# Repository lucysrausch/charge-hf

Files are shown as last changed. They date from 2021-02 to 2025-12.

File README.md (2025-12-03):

# GaN Class-D Wireless Power Amplifier

I designed this board because I wanted a signal generator that was more capable than just generating a static waveform.
For familiarizing myself with wireless power transfer and getting a feeling for antenna and magnetic design, I wanted a source-meausure-unit (SMU) for RF,
something that could generate and also measure RF output. I also wanted all settings and measurements to be easily controllable and readable such that I could easily script testbenches in python for plotting parameter sweeps, or prototype control loops critical for real-world WPT like resonance tracking or constant output power control.

I finished this project in winter 2020, and it became an invaluable tool throughout 2021 for designing a custom wireless charging solution.

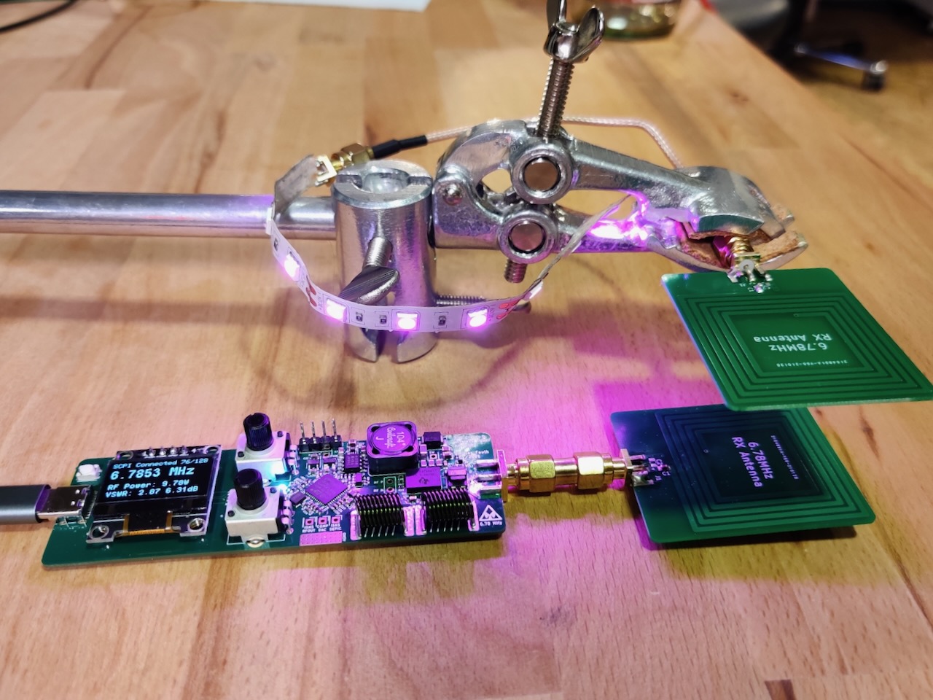
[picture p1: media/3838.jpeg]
WPT Demo Setup

*Assembled development board showing real-time status on OLED display: frequency, RF power, and VSWR measurements.*
*Demonstration setup: PCB spiral coil antennas (transmit and receive) wirelessly powering an LED strip at 6.78 MHz.

## Features

- **6.78 MHz ISM Band Operation** - Optimized for the AirFuel/Qi extended power profile frequency band
- **Software-Defined RF Generation** - Real-time frequency and deadtime adjustment via software
- **STM32G4 HRTIM** - Built around the STM32G474 with 184 ps RF PWM resolution (5.4 GHz effective clock)
- **Integrated SEPIC Converter** - Programmable amplifier supply voltage (0–20V) with input current limiting
- **SCPI over USB CDC** - Standard instrument control protocol for automated test benches
- **OLED Status Display** - Real-time frequency, power, and VSWR monitoring
- **Analog Knob Inputs** - Two potentiometers which can be read via SCPI to control any parameter. (or you can use these ADC inputs to measure ie. voltage and current in the WPT receiver and plot them along input power for efficiency sweeps

## Applications

- Wireless power transfer research and development
- Antenna impedance matching and tuning, efficiency testing
- Inductive heating experiments, plasma generation
- Generic educational RF / power electronics platform

## Hardware Specifications

| Parameter | Value |
|---|---|
| Operating Frequency | 10 kHz – 10 MHz |
| HRTIM Resolution | 184 ps (144 MHz × 32 multiplier) |
| Deadtime Range | 0–511 counts (×8 prescaler, ~1.1 ns steps) |
| Amplifier Supply | 0–20V (SEPIC regulated) |
| Input Current Limit | Programmable, default 3A |
| Input Voltage | 5V USB-C |
| Control Interface | USB CDC (Virtual COM Port) |
| MCU | STM32G474 (170 MHz Cortex-M4F) |

## PCB Design

### 3D Rendering

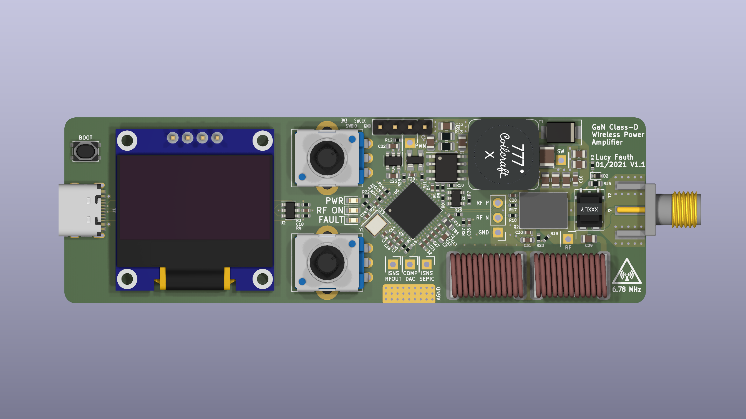
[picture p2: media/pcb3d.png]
3D PCB Render

*3D render of the assembled board with all components*

### Board Layout

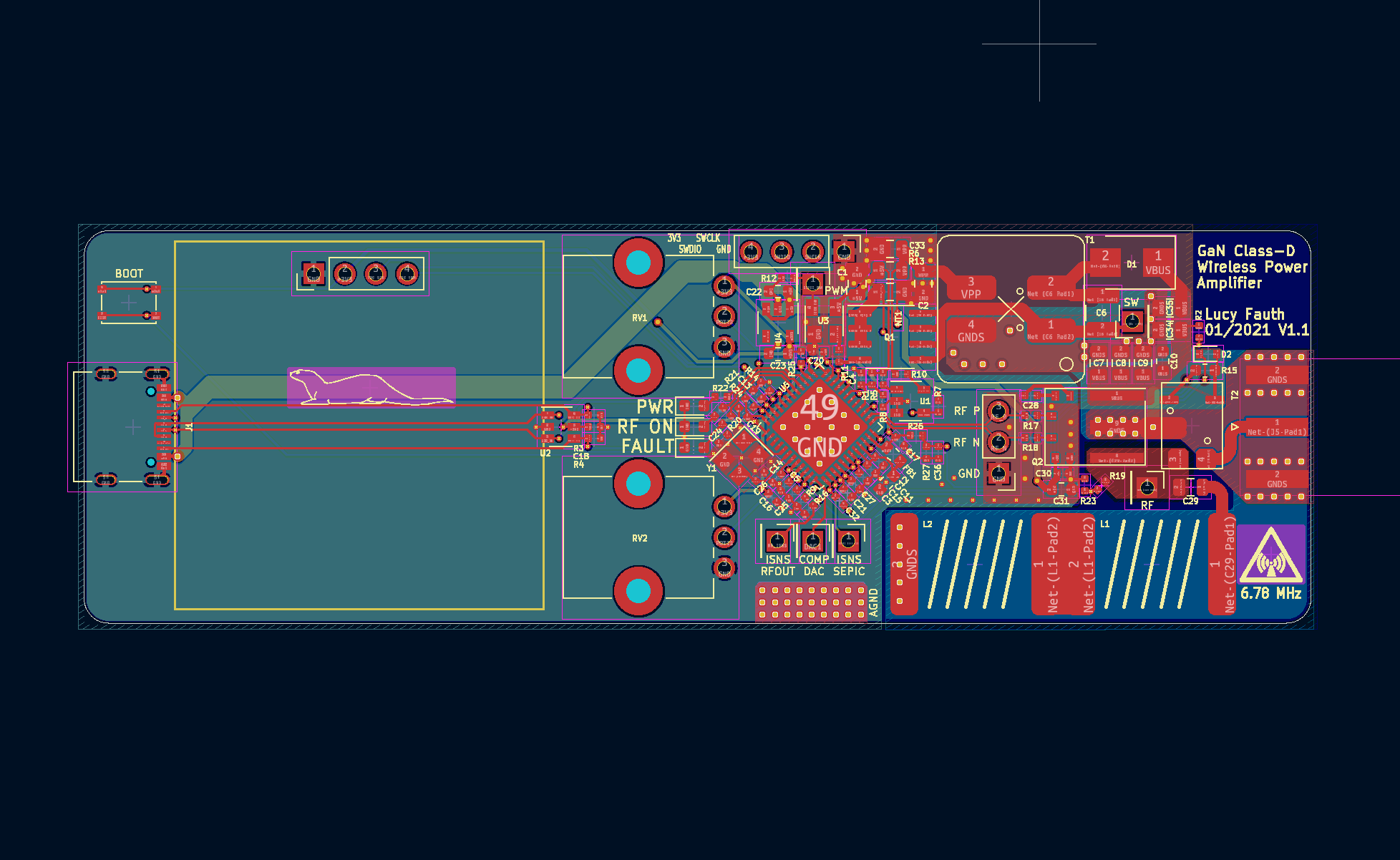
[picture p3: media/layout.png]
PCB Layout

*Full board layout showing component placement: USB-C input (left), OLED display, SEPIC converter (top right), STM32G4 MCU, GaN half-bridge (center right), and output matching network (bottom right)*

### Critical Design: Ground Plane and Return Path

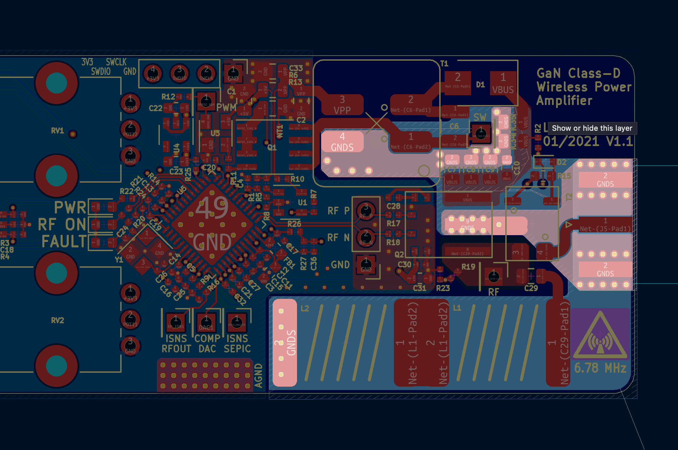
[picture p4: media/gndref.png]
GND Reference Plane

*PCB layout highlighting the ground plane structure around the GaN switching stage*

High-frequency switching at 6.78 MHz with fast edge rates demands careful attention to parasitic inductance in the power loop. Key design decisions implemented in this layout:

**Minimizing Loop Inductance:**
- **Tight Component Placement** - The GaN FETs, gate drivers, and decoupling capacitors are placed as close as possible to minimize the physical area of the switching current loop
- **Direct Via Stitching** - Multiple vias connect the top-side ground pads directly to the internal ground plane, reducing the inductance of the return path
- **Solid Ground Reference** - An unbroken ground plane beneath the switching node provides a low-inductance return path for high-frequency currents with a single net tie to DGND
- **Thermal Relief Considerations** - Ground connections to the FET source pads use sufficient via count to handle both thermal dissipation and the high-frequency return currents

## Schematic

📄 **[Download Full Schematic (PDF)](hardware/schematic_V1.2/charge-hf.pdf)**

The schematic is organized into functional blocks:

```
┌─────────────────┐   ┌─────────────────┐   ┌─────────────────┐   ┌─────────────────┐
│   USB-C Input   │──▶│   SEPIC DCDC    │──▶│  GaN Half-Bridge│──▶│   RF Output     │
│   + ESD Prot.   │   │   5V → 0-20V    │   │   LMG5200       │   │   I & U Sense   │
└────────┬────────┘   └────────┬────────┘   └────────┬────────┘   └─────────────────┘
         │                     │                     │
         │            ┌────────┴────────┐            │
         └───────────▶│   STM32G474     │-───────────┘
                      │   HRTIM + ADC   │
                      │   USB CDC SCPI  │
                      └─────────────────┘
```

## Circuit Design Notes

### Power Stage: LMG5200 GaN Half-Bridge

The heart of the RF amplifier is the **Texas Instruments LMG5200**, a fully integrated 80V/10A GaN half-bridge power stage. This device integrates both high-side and low-side GaN FETs along with their gate drivers in a single 6×8mm QFN package.

**Why use an integrated module?**

- **Minimized Parasitics** - The gate driver and GaN FETs are co-packaged with optimized bond wire lengths, achieving lower gate loop inductance than any discrete solution. This is critical at 6.78 MHz where even 1nH of stray inductance causes significant ringing.
- **Simplified Layout** - A single component eliminates the need to route high-speed gate drive signals across the PCB, reducing EMI and layout complexity.

### SEPIC DC-DC Converter

The amplifier supply (VPP) is generated by a SEPIC topology, chosen for its ability to both step-up and step-down. This allows operation from 5V USB while generating 0–20V for the GaN stage.

**Key components:**

- **Si4058 (Q1)** - Low Rds(on) N-channel MOSFET handles the primary switching
- **MIC4416 (U3)** - Low-side gate driver with enable control, driven directly from STM32 HRTIM Timer D

**Feedback and control:**

- **Voltage Sensing** - A resistive divider (100k/5.1k) scales VPP down to ADC range
- **Current Sensing** - A 10mΩ shunt (R13) with a Si8540 current sense amplifier measures input current for overcurrent protection and constant power control
- **Digital Control Loop** - The STM32 implements a PI controller in the HRTIM repetition interrupt, adjusting duty cycle based on voltage error with current limiting

### USB Power Input

The design operates from USB-C with proper PD support:

- **USBLC6-4 (U2)** - ESD protection on D+/D- and CC lines
- **CC1/CC2 Resistors (R3, R4)** - 5.1kΩ pull-downs advertise the device as a UFP (sink) for default 5V/3A
- **UCPD Peripheral** - The STM32G4's built-in USB-PD controller connects to CC1/CC2 for potential USB-PD negotiation (firmware support for higher voltages possible)

### RF Output Network

The Class-D output is filtered and can be impedance-matched to an antenna:

- **LC Resonant Tank (L1, L2, C29)** - Two 390nH inductors and a 1µF capacitor form a series-resonant network tuned near 6.78 MHz. The tank filters the square wave output and provides the sinusoidal current needed for efficient WPT.
- **CST7030-020LB (T2)** - A 1:20 turns ratio current transformer plus shunt resistor are used for sensing AC output current

### STM32G474 Configuration

The STM32G474CB provides the digital control:

- **HRTIM Timer C** - Generates complementary PWM for the GaN half-bridge with programmable deadtime
- **HRTIM Timer D** - Drives the SEPIC converter with separate frequency/duty control
- **ADC2** - Continuous DMA-driven sampling of voltages, currents, and potentiometer inputs
- **DAC1/DAC3** - Provide reference voltages for the analog comparators (overcurrent protection)
- **I2C1** - Drives the OLED status display
- **USB** - CDC virtual COM port for SCPI communication

## SCPI Command Reference

The amplifier implements SCPI (Standard Commands for Programmable Instruments) over USB CDC. Connect using any serial terminal or VISA library at the default USB CDC settings.

### Identification Commands

| Command | Description | Example Response |
|---|---|---|
| `*IDN?` | Query device identification | `Manufacturer,Model,Serial,Version` |
| `*RST` | Reset device to default state | - |
| `*TST?` | Self-test query | `0` (pass) or `1` (fail) |
| `*CLS` | Clear status registers | - |
| `*OPC?` | Operation complete query | `1` |

### Measurement Commands

| Command | Description | Returns |
|---|---|---|
| `MEASure:VOLTage:DC:INput?` | Read USB input voltage | Voltage in V (float) |
| `MEASure:VOLTage:DC:OUTput?` | Read amplifier supply voltage | Voltage in V (float) |
| `MEASure:CURRent:DC:INput?` | Read input current | Current in A (float) |
| `MEASure:VOLTage:DC:CONTrol? <n>` | Read potentiometer voltage | Voltage in V (float) |

**Example:**
```
> MEAS:VOLT:DC:IN?
< 5.032

> MEAS:VOLT:DC:OUT?
< 12.45

> MEAS:CURR:DC:IN?
< 0.856

> MEAS:VOLT:DC:CONT? 1
< 1.65
```

### Configuration Commands

| Command | Parameters | Description |
|---|---|---|
| `CONFigure:VOLTage:DC:OUTput <V>` | Voltage (0–30V) | Set amplifier supply voltage |
| `CONFigure:CURRent:DC:INput <A>` | Current (0–3A) | Set input current limit |
| `CONFigure:FREQuency <Hz>` | Frequency (10000–15000000) | Set RF output frequency |
| `CONFigure:DEADtime <rising>,<falling>` | 0–511 each | Set half-bridge deadtime |

**Example:**
```
> CONF:VOLT:DC:OUT 15
< OK

> CONF:FREQ 6780000
< OK

> CONF:DEAD 20,20
< OK
```

### System Commands

| Command | Description |
|---|---|
| `SYSTem:ERRor?` | Query and clear oldest error |
| `SYSTem:ERRor:COUNt?` | Query number of errors in queue |
| `SYSTem:VERSion?` | Query SCPI version |
| `STATus:QUEStionable?` | Query questionable status register |

## Python Examples

Example scripts are provided in the [`software/`](software/) directory demonstrating SCPI communication via PyVISA.

Thanks to SCPI integration for both setting parameters and reading output power, it is very easy to build custom testbenches to characterize ie. efficiency over frequency and plot the results using matplotlib or similar.

### Basic Control - [`control.py`](software/control.py)

This script provides interactive control using the two onboard potentiometers. It continuously reads the knob positions via `MEAS:VOLT:DC:CONTrol?`, maps them to frequency (1–8 MHz) and output voltage (0–30V), and updates the amplifier settings in real-time. The display shows actual measured values including calculated input power.

**Usage:**
```bash
python software/control.py
```

### Custom Scripts

For custom automation, connect using PyVISA with the `@py` backend:

```python
import pyvisa as visa
rm = visa.ResourceManager('@py')
amp = rm.open_resource("ASRL/dev/ttyACM0::INSTR")
print(amp.query("*IDN?"))
```

On Windows, the resource string will be `ASRL<n>::INSTR` where `<n>` is the COM port number assigned to the USB CDC device.

## Building the Firmware

### Prerequisites

- ARM GCC Toolchain
- STM32CubeMX (for regenerating HAL code if needed)
- OpenOCD or ST-Utils for flashing

### Compilation

```bash
cd firmware
make
```

### Flashing

```bash
# Using OpenOCD
openocd -f interface/stlink.cfg -f target/stm32g4x.cfg -c "program build/main.elf verify reset exit"

# Or using ST-Link utility
st-flash write build/main.bin 0x8000000
```

### Known bugs

The board features a push button connected to the boot select pin of the STM32. In theory, this would allow the STM32 to enter DFU mode and allow to flash the board without the need for a programmer. Unfortunatly, despite a strong pull-down resistor, the GPIO connected to the gate driver for the SEPIC DC-DC seems to go high when entering DFU. This turns on Q1, but without PWM, it just shorts the USB input and triggers an overcurrent event on the USB port the device is plugged into.

The workaround is to simply not assemble this button, and always flash the board via SWD.

## License

- Hardware design files: MIT license 
- Firmware: MIT license 
- Software: MIT license
- 3rd party Firmware: BSD 3-Clause (STM32 HAL), BSD 2-Clause (SCPI library)

## Author

Lucy Fauth - Rev 1.2 (February 2021)

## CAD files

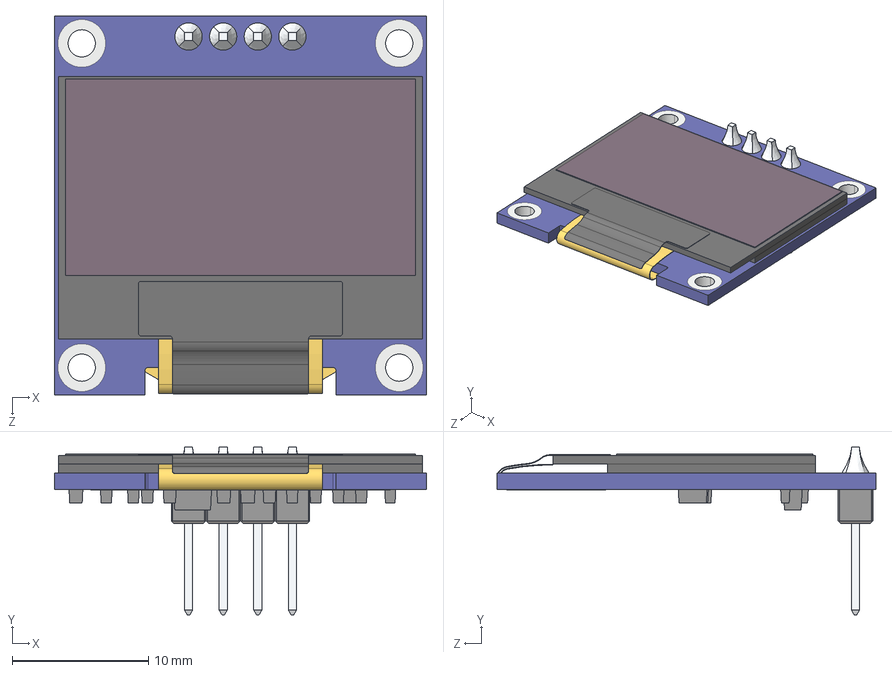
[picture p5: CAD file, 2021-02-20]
hardware/3d/OLED TFT 0.96 inch 64x128 monochrome.STEP
27.3 x 12.3 x 27.8 mm

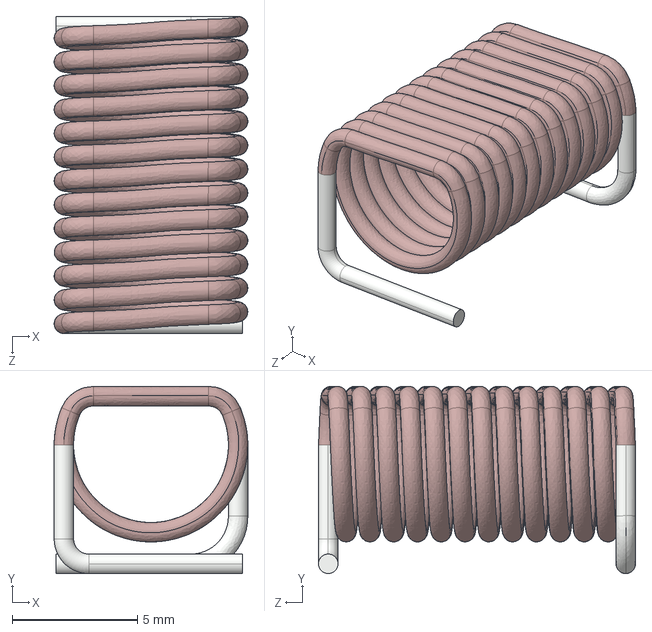
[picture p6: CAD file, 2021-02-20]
hardware/3d/Coilcraft-2929SQ-391.STEP
7.75 x 7.49 x 12.7 mm

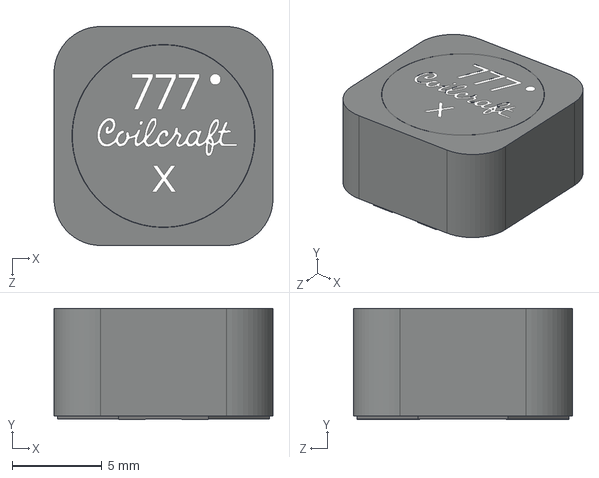
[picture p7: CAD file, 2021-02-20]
hardware/3d/Coilcraft-MSD1260.STEP
12.2 x 6.20 x 12.2 mm

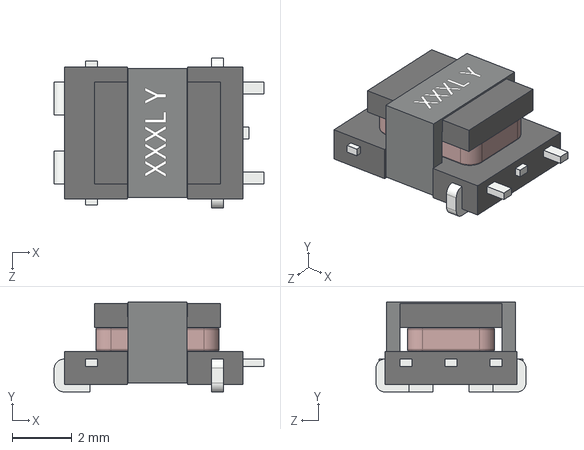
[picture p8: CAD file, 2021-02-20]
hardware/3d/Coilcraft-CST7030.STEP
7.00 x 3.00 x 5.00 mm

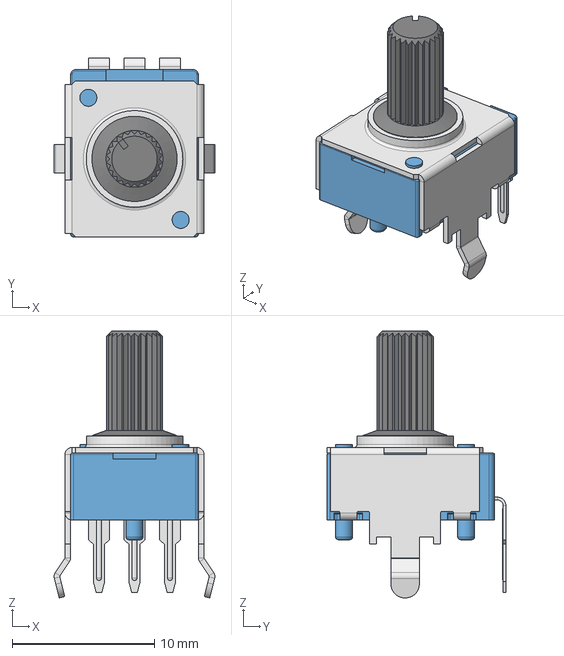
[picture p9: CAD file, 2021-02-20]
hardware/3d/R-0904N-L-15KS.step
11.3 x 12.6 x 18.8 mm

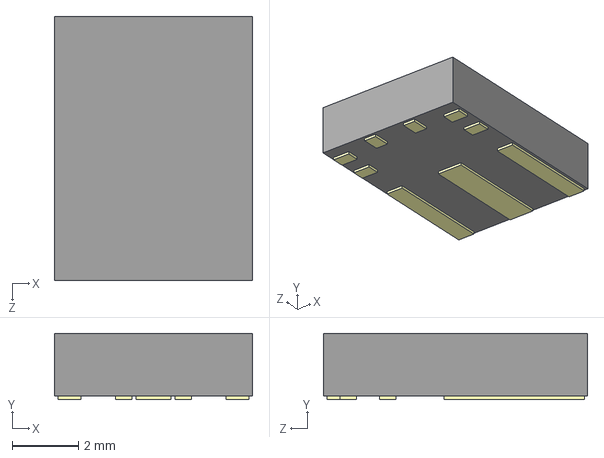
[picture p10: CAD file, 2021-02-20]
hardware/3d/User Library-QFM9_6x8x2mm_LMG5200.STEP
6.00 x 2.00 x 8.00 mm

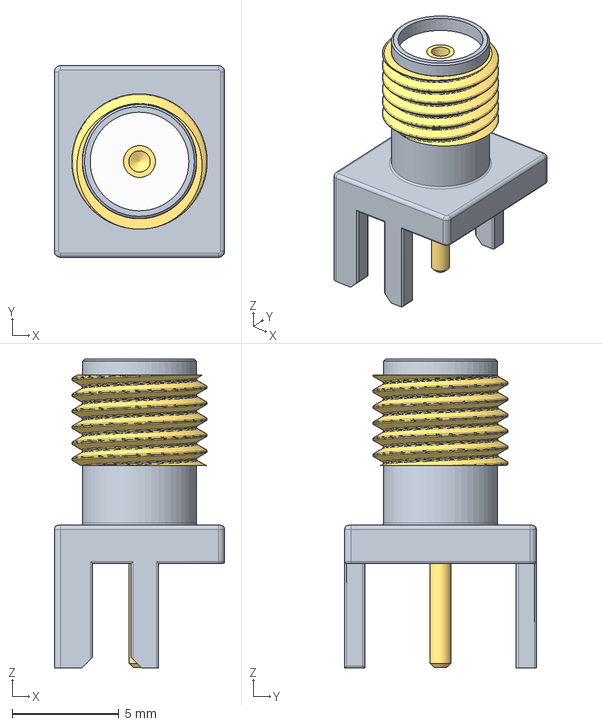
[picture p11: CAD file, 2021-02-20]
hardware/3d/SMA-20.stp
8.00 x 9.00 x 14.5 mm

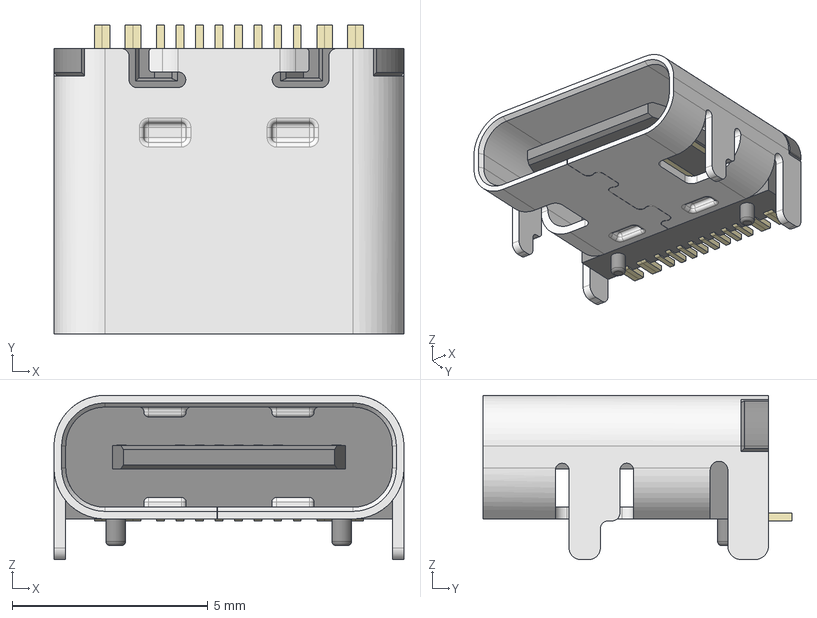
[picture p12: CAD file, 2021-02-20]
hardware/3d/HRO_TYPE-C-31-M-12.step
8.95 x 7.90 x 4.20 mm

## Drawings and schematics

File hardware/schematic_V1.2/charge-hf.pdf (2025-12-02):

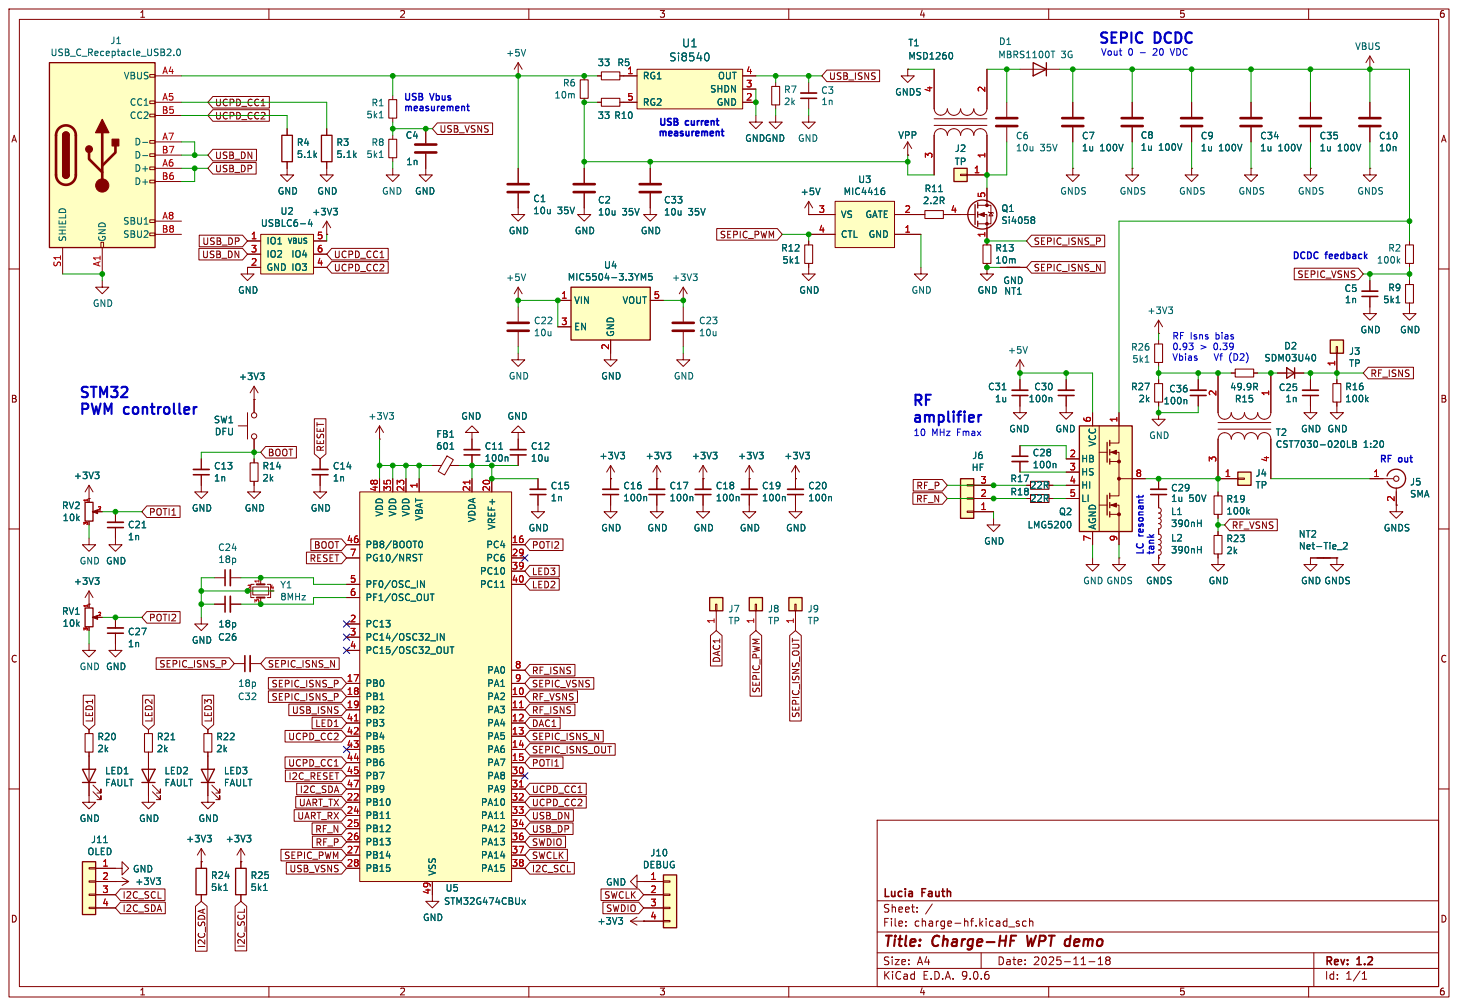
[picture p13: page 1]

1 3 RV1 2 10k GND GND GND GND

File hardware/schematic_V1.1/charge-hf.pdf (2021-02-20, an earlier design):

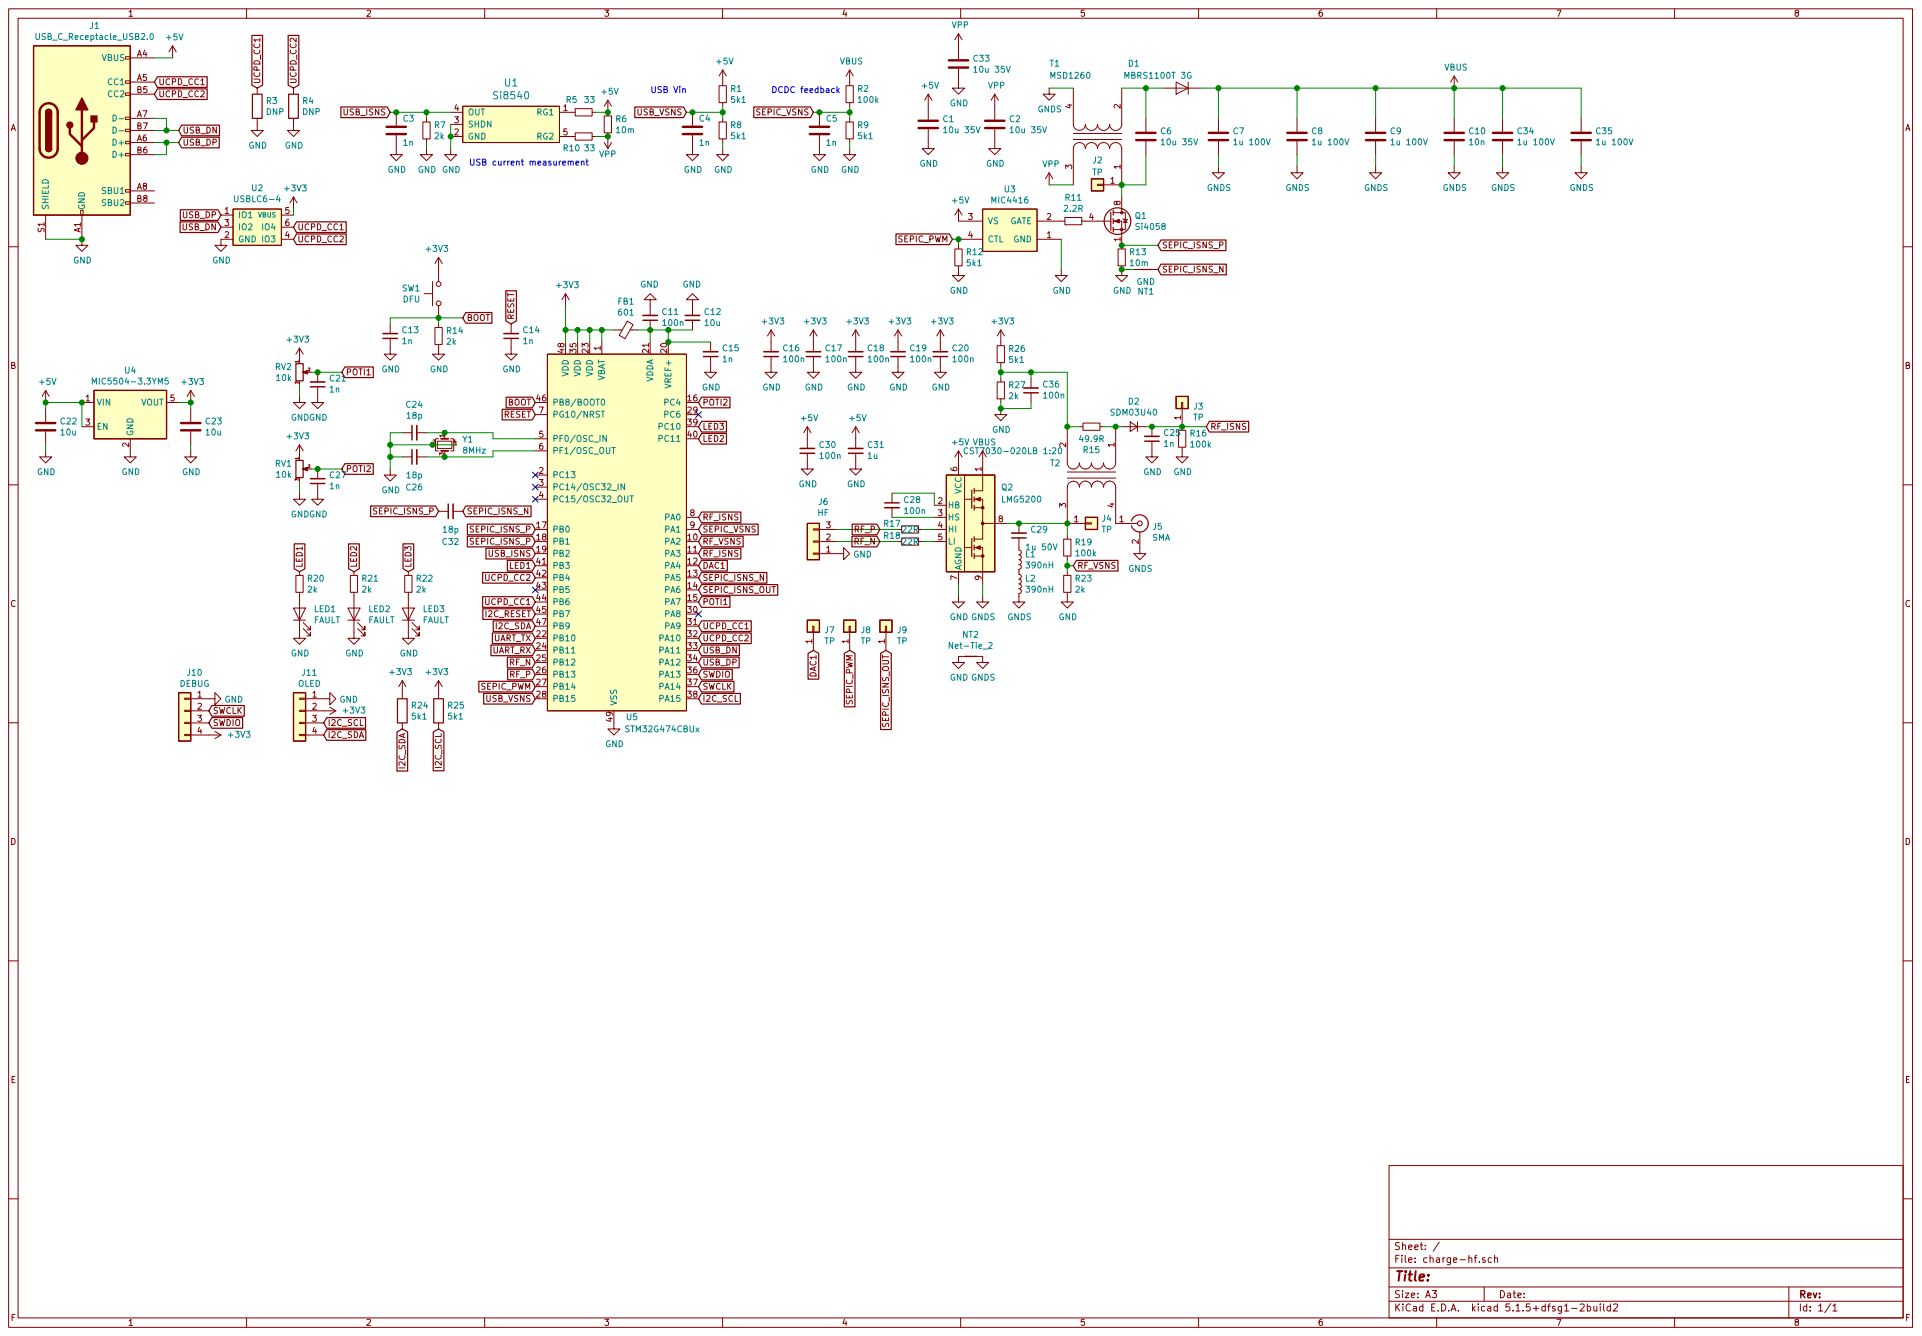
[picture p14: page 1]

File: charge-hf.sch Sheet: /

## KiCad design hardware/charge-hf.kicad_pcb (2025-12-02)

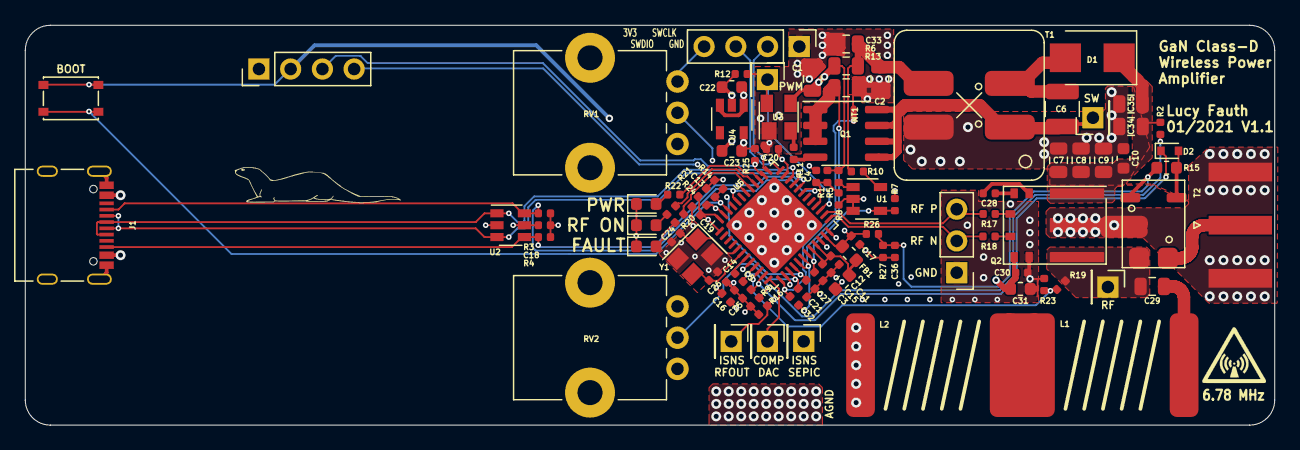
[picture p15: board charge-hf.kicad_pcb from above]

Board: 4 copper layers, 100.0 x 32.0 mm, 96 parts (0 on the bottom side), 55 nets.

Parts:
C1, C2, C33: 10u 35V; C_0805_2012Metric
C3, C4, C5, C13, C14, C15, C21, C25, C27: 1n; C_0402_1005Metric
C6: 10u 35V; C_1210_3225Metric
C7, C8, C9, C34, C35: 1u 100V; C_0805_2012Metric
C10: 10n; C_0603_1608Metric
C11, C16, C17, C18, C19, C20, C28, C30, C36: 100n; C_0402_1005Metric
C12, C22, C23: 10u; C_0603_1608Metric
C24, C26, C32: 18p; C_0402_1005Metric
C29: 1u 50V; C_0805_2012Metric
C31: 1u; C_0603_1608Metric
D1: MBRS1100T 3G; D_SMB
D2: SDM03U40; D_SOD-523
FB1: 601; L_0603_1608Metric
J1: USB_C_Receptacle_USB2.0; USB_C_Receptacle_Palconn_UTC16-G
J2, J3, J4, J7, J8, J9: TP; PinHeader_1x01_P2.54mm_Vertical
J5: SMA; SMA_Amphenol_132289_EdgeMount
J6: HF; PinHeader_1x03_P2.54mm_Vertical
J10: DEBUG; PinHeader_1x04_P2.54mm_Vertical
J11: OLED; PinHeader_1x04_P2.54mm_Vertical
L1, L2: 390nH; 2929SQ
LED1, LED2, LED3: FAULT; LED_0603_1608Metric
NT1: GND; NetTie-2_SMD_Pad0.5mm
Q1: Si4058; SOIC-8_3.9x4.9mm_P1.27mm
Q2: LMG5200; Texas_MOF0009A
R1, R8, R9, R12, R24, R25, R26: 5k1; R_0402_1005Metric
R2, R16, R19: 100k; R_0402_1005Metric
R3, R4: DNP; R_0402_1005Metric
R5, R10: 33; R_0402_1005Metric
R6, R13: 10m; R_0805_2012Metric
R7, R14, R20, R21, R22, R23, R27: 2k; R_0402_1005Metric
R11: 2.2R; R_0402_1005Metric
R15: 49.9R; R_0603_1608Metric
R17, R18: 22R; R_0402_1005Metric
RV1, RV2: 10k; Potentiometer_Bourns_PTV09A-1_Single_Vertical
SW1: DFU; SW_SPST_PTS810
T1: MSD1260
T2: CST7030-020LB 1:20; CST7030
U1: Si8540; SOT-23-5
U2: USBLC6-4; SOT-23-6
U3: MIC4416; SOT-143
U4: MIC5504-3.3YM5; SOT-23-5
U5: STM32G474CBUx; QFN-48-1EP_7x7mm_P0.5mm_EP5.6x5.6mm
Y1: 8MHz; Crystal_SMD_3225-4Pin_3.2x2.5mm

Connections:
+3V3: C16.2, C17.2, C18.2, C19.2, C20.2, C23.1, FB1.2, J10.4, J11.2, R24.1, R25.1, R26.1, RV1.1, RV2.1, SW1.1, U2.5, U4.5, U5.1, U5.23, U5.35, U5.48
+5V: C1.1, C22.1, C30.2, C31.2, J1.A4, J1.A9, J1.B4, J1.B9, Q2.6, R1.1, R5.2, R6.1, U3.3, U4.1, U4.3
BOOT: C13.2, R14.1, SW1.2, U5.46
DAC1: J7.1, U5.12
GND: C1.2, C2.2, C3.2, C4.2, C5.2, C11.2, C12.2, C13.1, C14.1, C15.1, C16.1, C17.1, C18.1, C19.1, C20.1, C21.1, C22.2, C23.2, C24.1, C25.1, C26.1, C27.1, C30.1, C31.1, C33.2, C36.1, J1.A1, J1.A12, J1.B1, J1.B12, J1.S1, J6.1, J10.1, J11.1, LED1.1, LED2.1, LED3.1, NT1.1, Q2.7, R3.2, R4.2, R7.2, R8.2, R9.2, R12.2, R13.2, R14.2, R16.2, R23.2, R27.2, RV1.3, RV2.3, U1.2, U1.3, U2.2, U3.1, U4.2, U5.49, Y1.2, Y1.4
GNDS: C7.2, C8.2, C9.2, C10.2, C34.2, C35.2, J5.2, L2.2, Q2.9, T1.4
I2C_SCL: J11.3, R25.2, U5.38
I2C_SDA: J11.4, R24.2, U5.47
LED1: R20.1, U5.41
LED2: R21.1, U5.40
LED3: R22.1, U5.39
unnamed: C6.1, D1.2, T1.2
unnamed: C6.2, J2.1, Q1.5, Q1.6, Q1.7, Q1.8, T1.1
unnamed: C11.1, C12.1, C15.2, FB1.1, U5.20, U5.21
unnamed: C24.2, U5.5, Y1.1
unnamed: C26.2, U5.6, Y1.3
unnamed: C28.1, Q2.2
unnamed: C28.2, Q2.3
unnamed: C29.1, L1.1
unnamed: C29.2, J4.1, Q2.8, R19.1, T2.3
unnamed: C36.2, R15.2, R26.2, R27.1, T2.2
unnamed: D2.2, R15.1, T2.1
unnamed: J5.1, T2.4
unnamed: L1.2, L2.1
unnamed: LED1.2, R20.2
unnamed: LED2.2, R21.2
unnamed: LED3.2, R22.2
unnamed: Q1.4, R11.1
unnamed: Q2.4, R17.1
unnamed: Q2.5, R18.1
unnamed: R5.1, U1.1
unnamed: R10.1, U1.5
unnamed: R11.2, U3.2
POTI1: C21.2, RV2.2, U5.15
POTI2: C27.2, RV1.2, U5.16
RESET: C14.2, U5.7
RF_ISNS: C25.2, D2.1, J3.1, R16.1, U5.8, U5.11
RF_N: J6.2, R18.2, U5.25
RF_P: J6.3, R17.2, U5.26
RF_VSNS: R19.2, R23.1, U5.10
SEPIC_ISNS_N: C32.2, NT1.2, U5.13
SEPIC_ISNS_OUT: J9.1, U5.14
SEPIC_ISNS_P: C32.1, Q1.1, Q1.2, Q1.3, R13.1, U5.17, U5.18
SEPIC_PWM: J8.1, R12.1, U3.4, U5.27
SEPIC_VSNS: C5.1, R2.2, R9.1, U5.9
SWCLK: J10.2, U5.37
SWDIO: J10.3, U5.36
UCPD_CC1: J1.A5, R3.1, U2.6, U5.31, U5.44
UCPD_CC2: J1.B5, R4.1, U2.4, U5.32, U5.42
USB_DN: J1.A7, J1.B7, U2.3, U5.33
USB_DP: J1.A6, J1.B6, U2.1, U5.34
USB_ISNS: C3.1, R7.1, U1.4, U5.19
USB_VSNS: C4.1, R1.2, R8.1, U5.28
VBUS: C7.1, C8.1, C9.1, C10.1, C34.1, C35.1, D1.1, Q2.1, R2.1
VPP: C2.1, C33.1, R6.2, R10.2, T1.3

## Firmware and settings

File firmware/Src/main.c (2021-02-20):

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

/* Includes ------------------------------------------------------------------*/
#include "main.h"

/* USER CODE BEGIN Includes */
#include "stm32g4xx_ll_hrtim.h"
#include <stdio.h>
#include <stdlib.h>
#include <string.h>
#include "usb_device.h"
/* USER CODE END Includes */

ADC_HandleTypeDef hadc1;
ADC_HandleTypeDef hadc2;
DMA_HandleTypeDef hdma_adc2;

COMP_HandleTypeDef hcomp1;
COMP_HandleTypeDef hcomp3;

DAC_HandleTypeDef hdac1;
DAC_HandleTypeDef hdac3;

HRTIM_HandleTypeDef hhrtim1;

I2C_HandleTypeDef hi2c1;

OPAMP_HandleTypeDef hopamp1;

PCD_HandleTypeDef hpcd_USB_FS;

/* USER CODE BEGIN PV */
/* SCPI bbuffer */
extern uint8_t UserRxBufferFS[APP_RX_DATA_SIZE];
extern uint8_t UserTxBufferFS[APP_TX_DATA_SIZE];
uint8_t is_new_data_ready;
uint16_t new_data_length;

volatile sepic_control_t sepic = {
  .Vset = 5.0, // 5V amplifier supply
  .Iset = 2.0  // 3A USB current limit
};

volatile knobs_t knobs;

volatile hf_control_t hf = {
  .freq = 6780000,  // 6.78 MHz
  .DTrising = 16, // rising deadtime, 0 - 511
  .DTfalling = 16 // falling deadtime, 0 - 511
};

uint16_t adc2_regular_buf[6];

/* USER CODE END PV */

void SystemClock_Config(void);
static void MX_GPIO_Init(void);
static void MX_DMA_Init(void);
static void MX_ADC1_Init(void);
static void MX_ADC2_Init(void);
static void MX_COMP1_Init(void);
static void MX_COMP3_Init(void);
static void MX_DAC1_Init(void);
static void MX_DAC3_Init(void);
static void MX_HRTIM1_Init(void);
static void MX_I2C1_Init(void);
static void MX_OPAMP1_Init(void);
static void MX_UCPD1_Init(void);
static void MX_USB_PCD_Init(void);
/* USER CODE BEGIN 0 */
void HAL_HRTIM_RepetitionEventCallback(HRTIM_HandleTypeDef * hhrtim, uint32_t TimerIdx) {
  if (TimerIdx == HRTIM_TIMERINDEX_TIMER_D) {
    //sepic.Icycle = (adc2_regular_buf[0] * VDDA)/0xFFF;
    //sepic.Icycle = sepic.Icycle / (0.01 * 64.0); // 10m sense, OPAMP2 64 Gain

    sepic.Vout = (adc2_regular_buf[0] * VDDA)/0xFFF;
    sepic.Vout = (sepic.Vout / (5100.0 / (100000.0 + 5100.0))) * 1.207; // 100k by 5k1 divider

    sepic.Iin = (adc2_regular_buf[1] * VDDA)/0xFFF;
    sepic.Iin = sepic.Iin / (0.01 * (2000.0 / 33.0)); // Si8540, 10m sense, 2k Rout, 33R Rg

    sepic.Vin = (adc2_regular_buf[2] * VDDA)/0xFFF;
    sepic.Vin = sepic.Vin / (5100.0 / (5100.0 + 5100.0)); // 5k1 by 5k1 divider

    float PID_I = 2.2;

    if (sepic.Iin < sepic.Iset) {
      sepic.error += (sepic.Vset - sepic.Vout) * PID_I;
    } else {
      sepic.error += (sepic.Iset - sepic.Iin) * 1000.0;
    }

    if (sepic.error < 0) {
      sepic.error = 0;
    } else if (sepic.error > 16000) {
      sepic.error = 16000;
    }
    uint32_t compare = sepic.error + 100;
    //if (sepic.Iin > sepic.Iset) {
    //  LL_HRTIM_TIM_SetCompare1(HRTIM1, LL_HRTIM_TIMER_D, 100);
    //} else
    if (compare < (SEPIC_PERIOD * 0.9f) && compare > 100) {
      LL_HRTIM_TIM_SetCompare1(HRTIM1, LL_HRTIM_TIMER_D, compare);
    }
  }
}

/* USER CODE END 0 */

/**
  * @brief  The application entry point.
  * @retval int
  */
int main(void)
{
  /* MCU Configuration--------------------------------------------------------*/

  /* Reset of all peripherals, Initializes the Flash interface and the Systick. */
  HAL_Init();

  /* Configure the system clock */
  SystemClock_Config();

  /* Initialize all configured peripherals */
  MX_GPIO_Init();
  MX_DMA_Init();
  MX_ADC1_Init();
  MX_ADC2_Init();
  MX_COMP1_Init();
  MX_COMP3_Init();
  MX_DAC1_Init();
  MX_DAC3_Init();
  MX_HRTIM1_Init();
  MX_I2C1_Init();
  MX_OPAMP1_Init();
  MX_UCPD1_Init();
  MX_USB_PCD_Init();
  /* USER CODE BEGIN 2 */
  MX_USB_Device_Init();

  SCPI_Init(&scpi_context,
      scpi_commands,
      &scpi_interface,
      scpi_units_def,
      SCPI_IDN1, SCPI_IDN2, SCPI_IDN3, SCPI_IDN4,
      scpi_input_buffer, SCPI_INPUT_BUFFER_LENGTH,
      scpi_error_queue_data, SCPI_ERROR_QUEUE_SIZE);

  /* Run the ADC2 calibration in single-ended mode */
  HAL_ADCEx_Calibration_Start(&hadc2, ADC_SINGLE_ENDED);

  /* Start ADC2 Injected Conversions */
  HAL_ADCEx_InjectedStart(&hadc2);

  /* HRTIM start-up */
  /* Enable HRTIM's outputs TC1, TC2 and TD1 */
  LL_HRTIM_EnableOutput(HRTIM1,
                          LL_HRTIM_OUTPUT_TC1
                        | LL_HRTIM_OUTPUT_TC2
                        | LL_HRTIM_OUTPUT_TD1);

  //LL_HRTIM_EnableIT_REP(HRTIM1, LL_HRTIM_TIMER_C);
  LL_HRTIM_EnableIT_REP(HRTIM1, LL_HRTIM_TIMER_D);
  LL_HRTIM_TIM_CounterEnable(HRTIM1, LL_HRTIM_TIMER_C);
  LL_HRTIM_TIM_CounterEnable(HRTIM1, LL_HRTIM_TIMER_D);

  //LL_HRTIM_TIM_SetCompare1(HRTIM1, LL_HRTIM_TIMER_D, SEPIC_PERIOD/2);

  HAL_ADC_Start_DMA(&hadc2, (uint32_t *)adc2_regular_buf, 5);

  /* USER CODE END 2 */

  /* Infinite loop */
  /* USER CODE BEGIN WHILE */

  HAL_GPIO_WritePin(LED3_GPIO_Port, LED3_Pin, 1);
  uint32_t i = 0;
  while (1)
  {
    i++;
    if (i % 100000 == 0) {
      knobs.knob1 = (adc2_regular_buf[3] * VDDA)/0xFFF;
      knobs.knob2 = (adc2_regular_buf[4] * VDDA)/0xFFF;
    }

    if (i % 1000000 == 0) {
      HAL_GPIO_TogglePin(LED2_GPIO_Port, LED2_Pin);
    }
    /* USER CODE END WHILE */

    /* USER CODE BEGIN 3 */
    if (is_new_data_ready) {
      SCPI_Input(&scpi_context, UserRxBufferFS, new_data_length);
      is_new_data_ready = 0;
    }
  }
  /* USER CODE END 3 */
}

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


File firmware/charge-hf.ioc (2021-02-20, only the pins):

Mcu.UserName=STM32G474CBUx
PA0.Signal=COMP3_INP
PA1.Signal=ADC2_IN2
PA10.Signal=UCPD1_DBCC2
PA11.Signal=USB_DM
PA12.Signal=USB_DP
PA13.Signal=SYS_JTMS-SWDIO
PA14.Signal=SYS_JTCK-SWCLK
PA15.Signal=I2C1_SCL
PA2.Signal=ADC1_IN3
PA3.Signal=OPAMP1_VINP
PA4.Signal=COMP_DAC11_group
PA7.Signal=ADC2_IN4
PA9.Signal=UCPD1_DBCC1
PB1.Signal=COMP1_INP
PB12.Signal=HRTIM1_CHC1
PB13.Signal=HRTIM1_CHC2
PB14.Signal=HRTIM1_CHD1
PB15.Signal=ADC2_IN15
PB2.Signal=ADC2_IN12
PB3.GPIO_Label=LED1
PB3.Signal=GPIO_Output
PB4.Signal=UCPD1_CC2
PB5.Signal=GPIO_Output
PB6.Signal=UCPD1_CC1
PB7.Signal=GPIO_Output
PB8-BOOT0.GPIO_Label=BOOT
PB8-BOOT0.Signal=GPIO_Input
PB9.Signal=I2C1_SDA
PC10.GPIO_Label=LED3
PC10.Signal=GPIO_Output
PC11.GPIO_Label=LED2
PC11.Signal=GPIO_Output
PC4.Signal=ADC2_IN5
PF0-OSC_IN.Signal=RCC_OSC_IN
PF1-OSC_OUT.Signal=RCC_OSC_OUT

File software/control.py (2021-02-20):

import pyvisa as visa
import time

rm = visa.ResourceManager('@py')
smu = rm.open_resource("ASRL/dev/ttyACM0::INSTR")

print(smu.query("*IDN?"))

voltage = float(smu.query("MEAS:VOLT:DC:IN?"))
print("Input voltage: %fV" % voltage)

while True:
    knob1 = float(smu.query("MEAS:VOLT:DC:CONTrol? 1"))
    knob2 = float(smu.query("MEAS:VOLT:DC:CONTrol? 2"))
    setvoltage = knob1 * 10.0
    setfreq = knob2 * 2000000 + 1000000
    smu.write("CONF:FREQ %i" % (setfreq))
    smu.write("CONF:VOLT:DC:OUT %i" % (setvoltage))
    time.sleep(0.1)

    isvoltage = float(smu.query("MEAS:VOLT:DC:OUT?"))
    iscurrent = float(smu.query("MEAS:CURR:DC:IN?"))
    print("Amplifier Voltage: %fV, Power: %fW, Frequency: %fMHz" % (isvoltage, iscurrent * 5.0, setfreq / 1000000.0), end='\r')

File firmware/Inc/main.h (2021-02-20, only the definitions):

#define LED3_Pin GPIO_PIN_10
#define LED3_GPIO_Port GPIOC
#define LED2_Pin GPIO_PIN_11
#define LED2_GPIO_Port GPIOC
#define LED1_Pin GPIO_PIN_3
#define LED1_GPIO_Port GPIOB
#define BOOT_Pin GPIO_PIN_8
#define BOOT_GPIO_Port GPIOB
#define VDDA            ((float)3.3f)
#define HF_PERIOD       ((uint32_t)680)
#define SEPIC_PERIOD    ((uint32_t)16383)
#define SEPIC_VMAX      ((float)    60.0)
#define SEPIC_IMAX      ((float)     3.0)
#define HF_FMAX         ((uint32_t)10000000)

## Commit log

2021-02-12 Add SCPI lib and USB CDC support
    [scpi.g]
2021-02-20 add kicad design files
    [Coilcraft-2929SQ-391.STEP, Coilcraft-CST7030.STEP, Coilcraft-MSD1260.STEP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]
2025-12-02 ADD: pictures and refactored schematic
    [charge-hf.kicad_pcb, charge-hf.kicad_sch]

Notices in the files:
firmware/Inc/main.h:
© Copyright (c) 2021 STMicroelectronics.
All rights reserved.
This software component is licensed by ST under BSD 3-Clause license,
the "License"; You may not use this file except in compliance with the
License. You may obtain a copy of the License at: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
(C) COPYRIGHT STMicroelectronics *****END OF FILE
